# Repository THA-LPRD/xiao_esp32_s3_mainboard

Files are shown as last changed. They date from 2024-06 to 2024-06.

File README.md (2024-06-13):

# XIAO ESP32-S3 Main Board PCB
## Main Board PCB for the first project at Technical University of Applied Science Augsburg
### Explanation
This repo contains the KiCad 8 files for the Main Board of the project. \
Necessary files are located in the src folder, whilst the 3D-models, symbols and footprints can be found in the models, symbols, and footprints folders. 
### Functionality
The Main Board is designed to be a host board for XIAO ESP32-S3 board. \
XIAO ESP32-S3 Documentation can be found under this link: https://wiki.seeedstudio.com/xiao_esp32s3_getting_started/ \
The PCB is designed to be powered by a battery (I used two Li-Ion 5400 mAh batteries connected in parallel and connected to a 1S 2 MOSFETs BMS). \
The main functionality of the board is to power an e-paper display and upload pictures to it using SPI protocol. The e-paper display in question is this one: https://www.waveshare.com/7.3inch-e-paper-hat-f.htm \
The PCB is equipped with an external button, which I used to refresh the display on demand (show a new picture), a switch that switches between 3.3V and 5V as Vcc for the display, as some Waveshare displays need 5V to operate. \
There are no mounting holes as the PCB is mounted in a 3D printed housing.
### TODOs
The main branch contains the old schematic with no subsheets and is a bit unpleasant to follow. I added subsheets to the feature_subsheets branch but updating the PCB from that schematic will cause problems with the net names and connections.

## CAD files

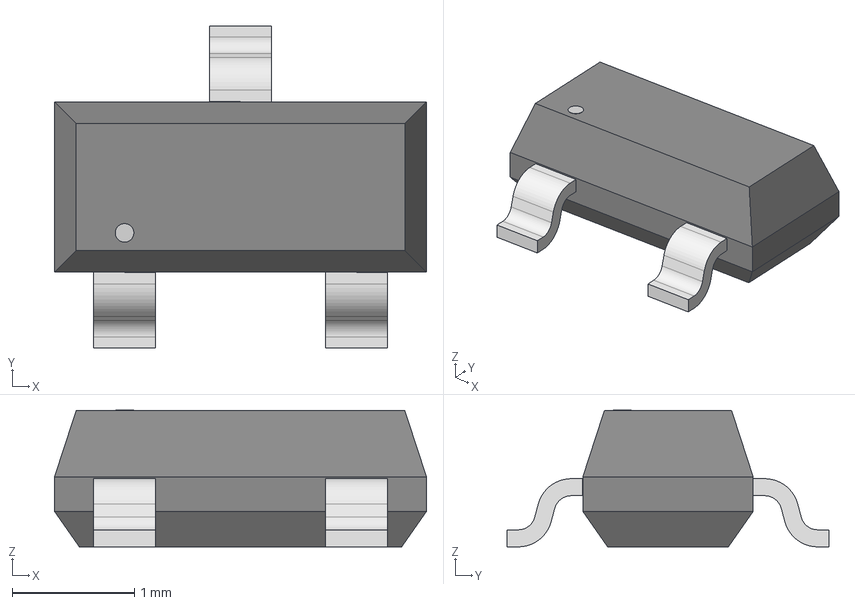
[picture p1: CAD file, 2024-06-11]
models/SOT_02K-T1-GE3_VIS.step
3.05 x 2.64 x 1.12 mm

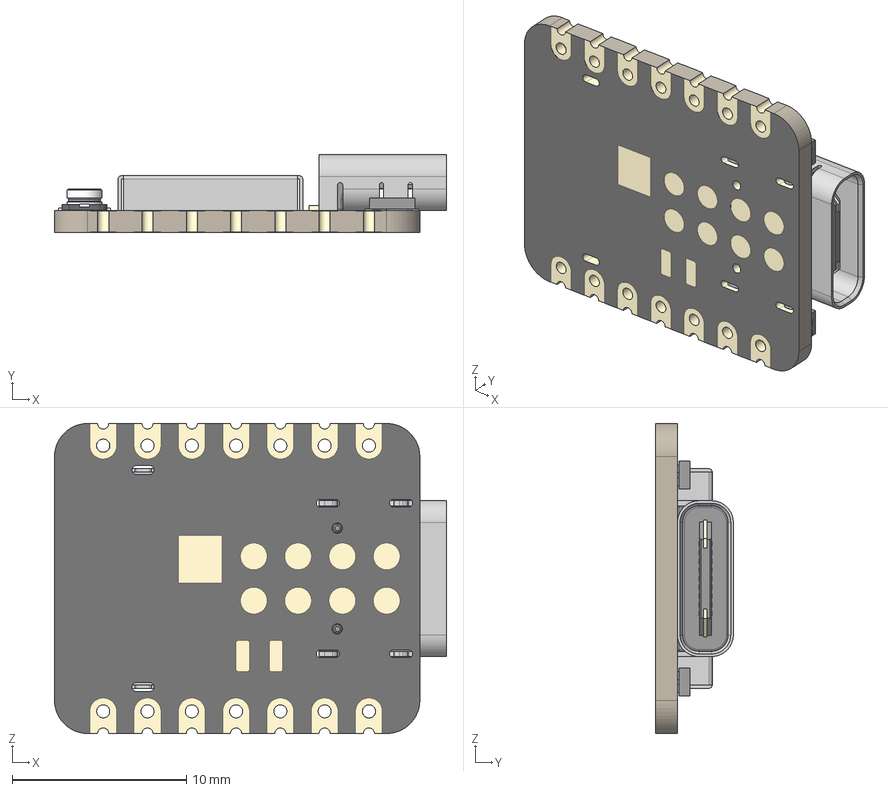
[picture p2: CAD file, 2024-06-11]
models/XIAO-ESP32S3 v2.step
22.5 x 4.46 x 17.8 mm
BOSS-EXTRUDE14_8_
BOSS-EXTRUDE7_4_
BOSS-EXTRUDE7_3_
BOSS-EXTRUDE14_4_
BOSS-EXTRUDE14_2_
BOSS-EXTRUDE14_11_
BOSS-EXTRUDE7_7_
BOSS-EXTRUDE14_9_
BOSS-EXTRUDE14_3_
BOSS-EXTRUDE14_7_
MIRROR2
BOSS-EXTRUDE14_5_
BOSS-EXTRUDE14_12_
BOSS-EXTRUDE7_8_
BOSS-EXTRUDE7_1_
BOSS-EXTRUDE14_10_
BOSS-EXTRUDE7_9_
BOSS-EXTRUDE14_6_
BOSS-EXTRUDE14_1_
BOSS-EXTRUDE7_6_
BOSS-EXTRUDE7_2_
CUT-EXTRUDE5
BOSS-EXTRUDE7_5_
Shield
Pins x 2
U.FL-R-SMT-1_10_ v1

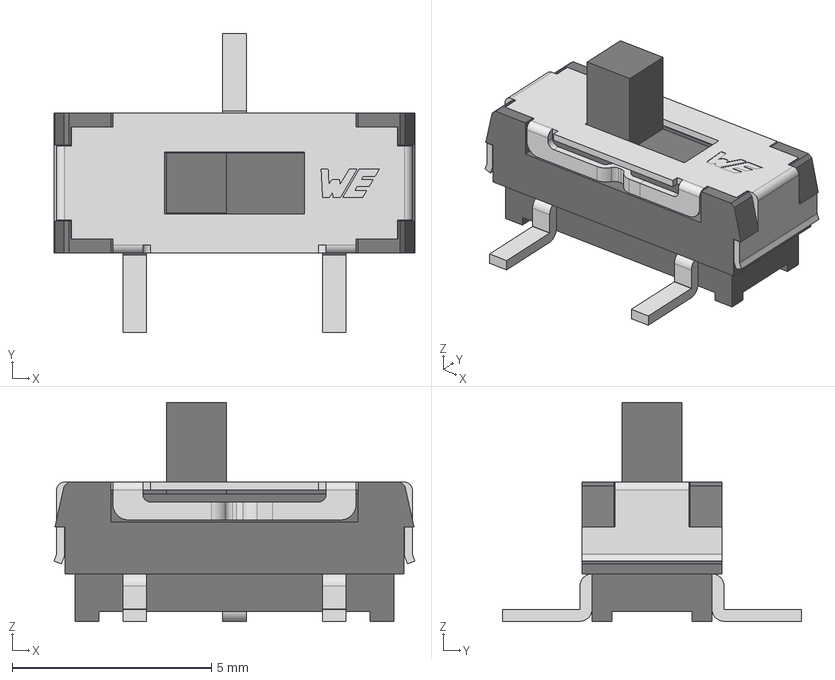
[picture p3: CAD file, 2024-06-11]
models/WS-SLSV_450406020024 (rev1).stp
9.05 x 7.50 x 5.50 mm
Base
Actuator
cover

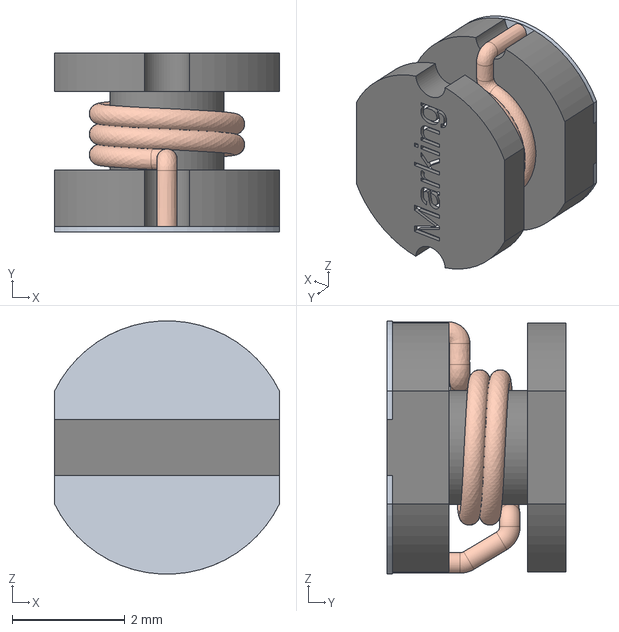
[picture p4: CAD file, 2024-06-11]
models/744773033--3DModel-STEP-56544.step
4.00 x 3.18 x 4.49 mm

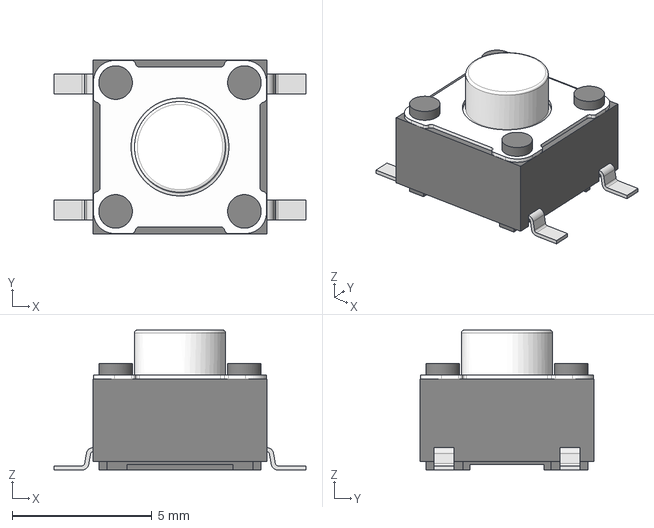
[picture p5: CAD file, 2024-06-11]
models/430182050816 (rev1).stp
9.00 x 6.20 x 5.00 mm

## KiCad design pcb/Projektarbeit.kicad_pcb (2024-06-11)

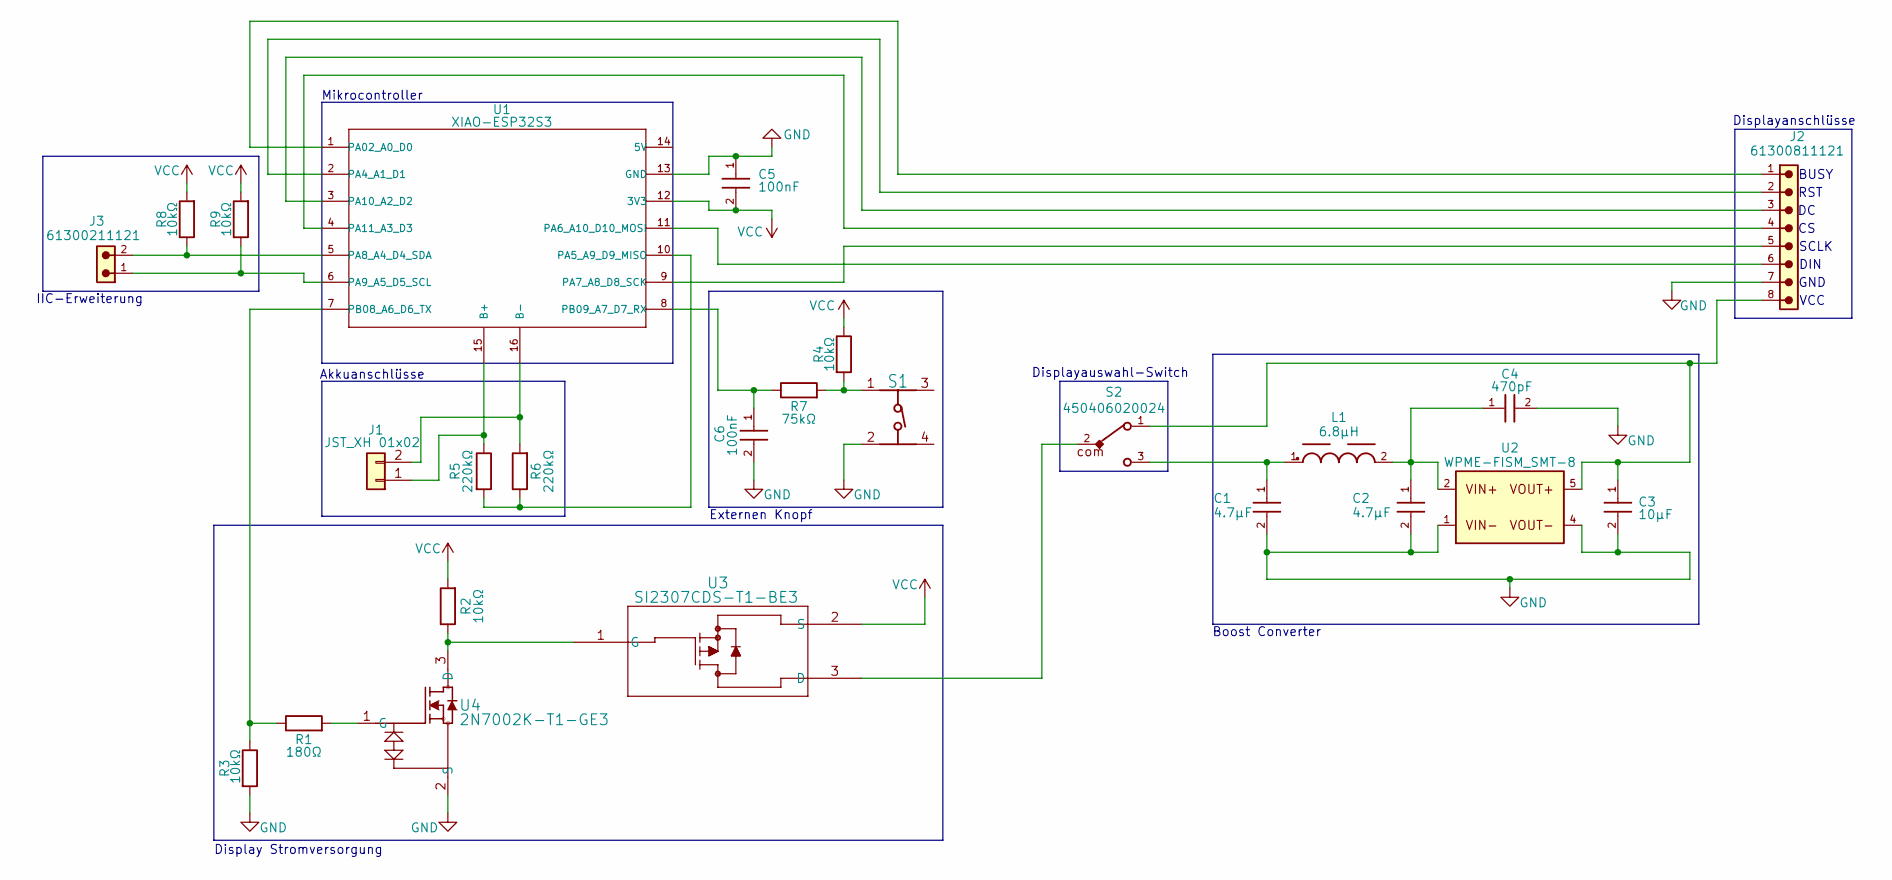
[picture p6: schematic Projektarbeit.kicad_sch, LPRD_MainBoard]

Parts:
C1, C2: 4.7µF; WCAP-CSGP_1210_H2.0
C3: 10µF; WCAP-CSGP_1210_H2.0
C4: 470pF; WCAP-CSMH_1808_H2.0
C5, C6: 100nF; WCAP-CSGP_1210_H2.0
J1: JST_XH 01x02; JST_XH_B2B-XH-A_1x02_P2.50mm_Vertical
J2: 61300811121; PART-NUMBER 61300811121
J3: 61300211121; PART-NUMBER 61300211121
L1: 6.8µH; WE-PD2_4532
R1: 180Ω; R_0805_2012Metric_Pad1.20x1.40mm_HandSolder
R2, R3, R4, R8, R9: 10kΩ; R_0805_2012Metric_Pad1.20x1.40mm_HandSolder
R5, R6: 220kΩ; R_0805_2012Metric_Pad1.20x1.40mm_HandSolder
R7: 75kΩ; R_0805_2012Metric_Pad1.20x1.40mm_HandSolder
S1: 430182050816
S2: 450406020024; PART-NUMBER 450406020024
U1: XIAO-ESP32S3; XIAO-Generic-Thruhole-14P-2.54-21X17.8MM
U2: WPME-FISM_SMT-8; WPME-FISM_SMT-8_L13.2W11.4H7.25
U3: SI2307CDS-T1-BE3; SOT-23_VIS
U4: 2N7002K-T1-GE3; SOT_02K-T1-GE3_VIS

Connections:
GND: C1.2, C2.2, C3.2, C4.2, C5.1, C6.2, J2.7, R3.2, S1.2, U1.13 (GND), U2.1, U2.4, U4.2 (S)
unnamed: C1.1, L1.1, S2.3
unnamed: C2.1, C4.1, L1.2, U2.2
unnamed: C3.1, J2.8, S2.1, U2.5
unnamed: J1.1, R5.1, U1.15 (B+)
unnamed: J1.2, R6.2, U1.16 (B-)
unnamed: R4.2, R7.2, S1.1
unnamed: J2.1, U1.1 (PA02_A0_D0)
unnamed: J2.2, U1.2 (PA4_A1_D1)
unnamed: R5.2, R6.1, U1.10 (PA5_A9_D9_MISO)
unnamed: J2.6, U1.11 (PA6_A10_D10_MOSI)
unnamed: J2.5, U1.9 (PA7_A8_D8_SCK)
unnamed: J3.2, R8.1, U1.5 (PA8_A4_D4_SDA)
unnamed: J3.1, R9.1, U1.6 (PA9_A5_D5_SCL)
unnamed: J2.3, U1.3 (PA10_A2_D2)
unnamed: J2.4, U1.4 (PA11_A3_D3)
unnamed: R1.1, R3.1, U1.7 (PB08_A6_D6_TX)
unnamed: C6.1, R7.1, U1.8 (PB09_A7_D7_RX)
unnamed: S2.2, U3.3 (D)
unnamed: R2.1, U3.1 (G), U4.3 (D)
unnamed: R1.2, U4.1 (G)
VCC: C5.2, R2.2, R4.1, R8.2, R9.2, U1.12 (3V3), U3.2 (S)

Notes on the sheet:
Displayauswahl-Switch
Akkuanschlüsse
Externen Knopf
BUSY
SCLK
DIN
VCC
RST
Boost Converter
GND
Display Stromversorgung
IIC-Erweiterung
Mikrocontroller
Displayanschlüsse

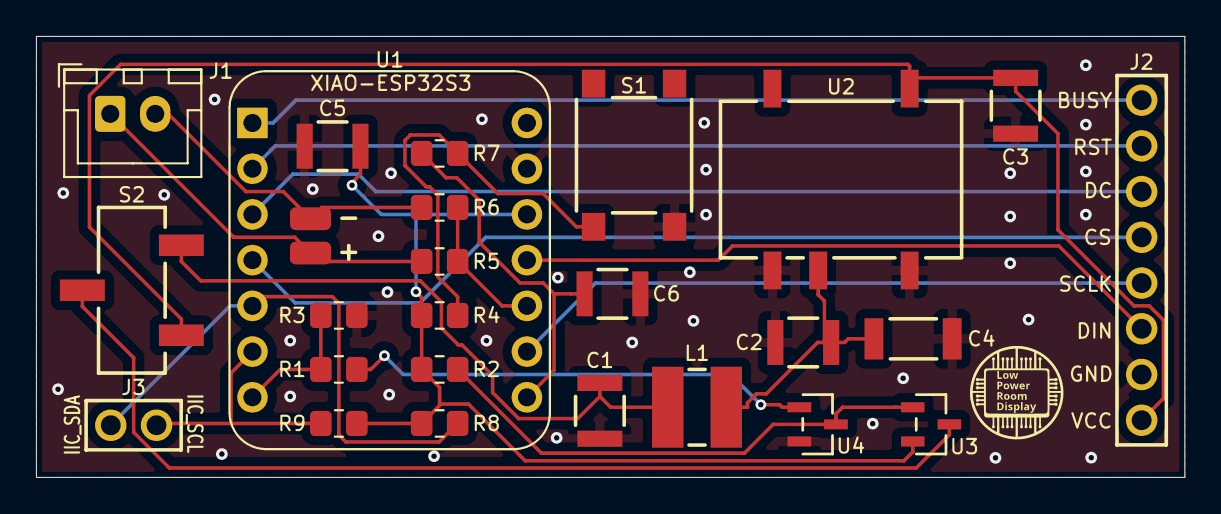
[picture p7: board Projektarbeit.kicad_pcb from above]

Board: 2 copper layers, 63.8 x 24.5 mm, 25 parts (0 on the bottom side), 22 nets.
